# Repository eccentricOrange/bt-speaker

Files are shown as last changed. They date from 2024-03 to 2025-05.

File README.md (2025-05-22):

# Speaker Driver

This is a simple analog speaker driver, mostly driven simply by the goal of learning more about this field.

## Features

### Cross-over filtration
The driver is designed to support two drivers, one for bass and one for treble. The cross-over frequency is **1326 Hz**, and is achieved by using simple first order filters.

*   Capacitor: 10 uF
*   Resistor: 12R

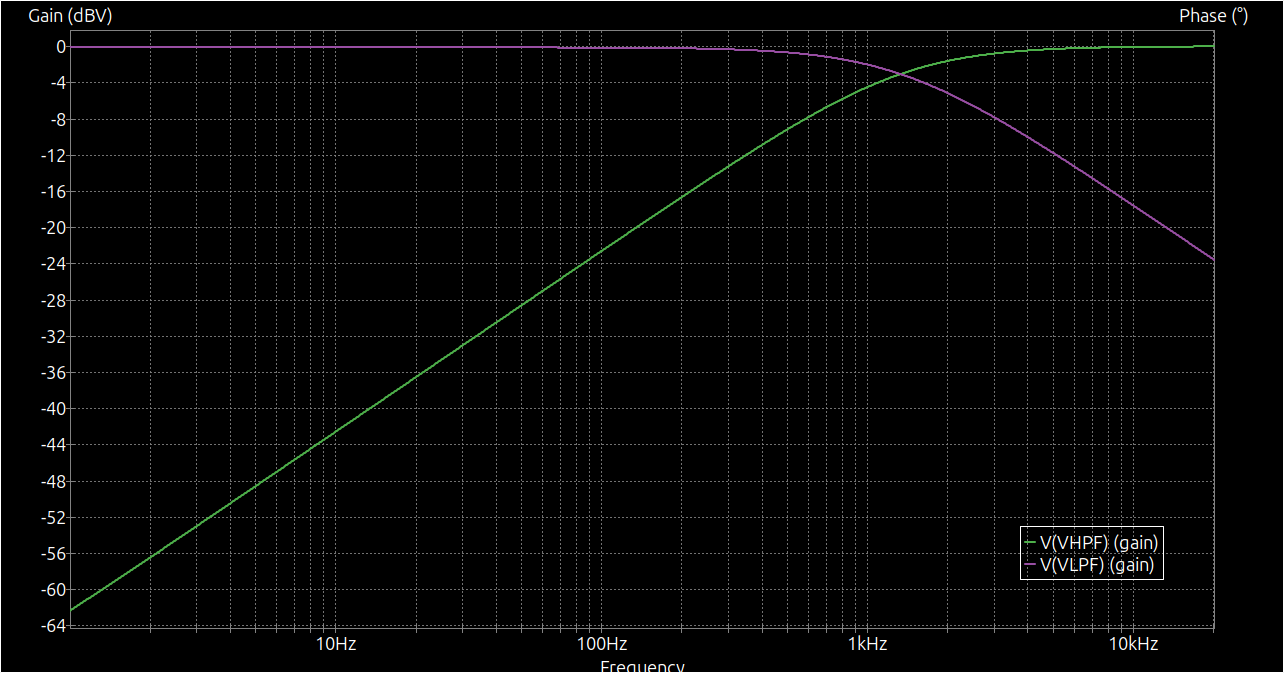
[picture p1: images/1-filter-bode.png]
bode


### Voltage pre-amplification
The input voltage is amplified by a factor of 6, using a simple non-inverting amplifier (LM741 op-amp). It is expected that the input voltage is around **1 V amplitude (2 Vpp)**, delivered by a 3.5 mm audio connector.

*   Input resistor: 820R
*   Fixed feedback resistor: 10k
*   Variable feedback resistor: 10k (in parallel with the fixed resistor)

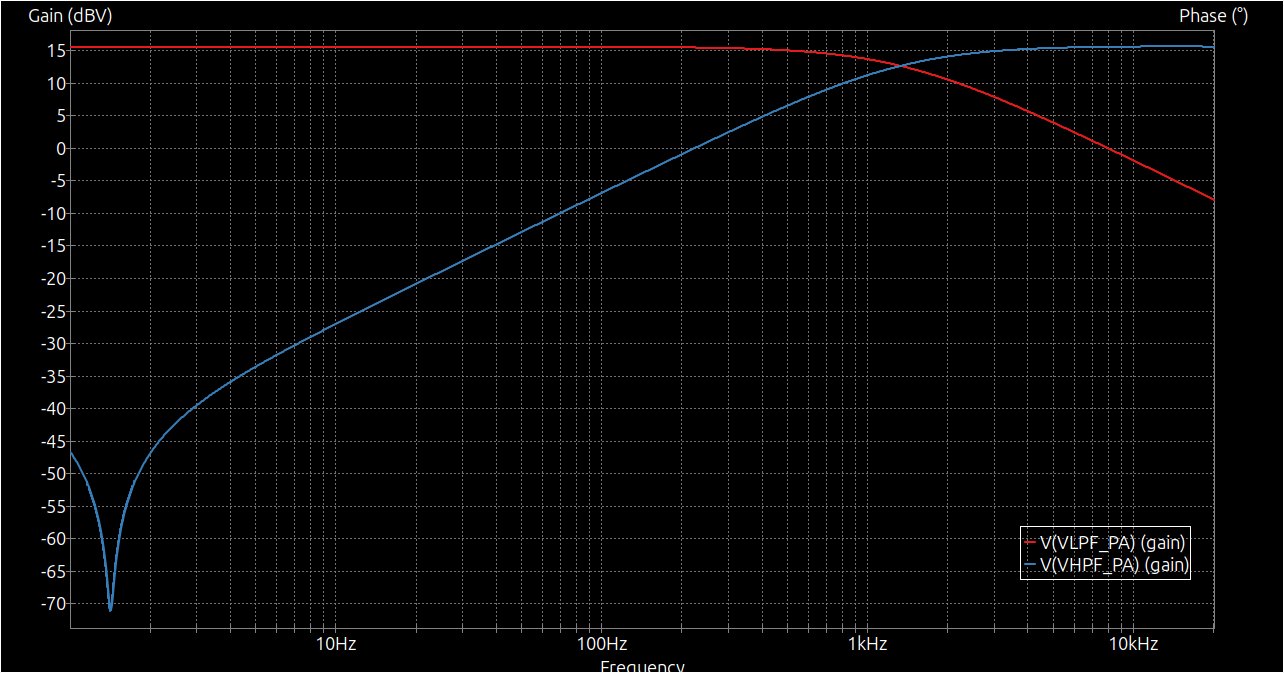
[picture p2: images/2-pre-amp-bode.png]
bode


### Power amplification
The next stage is a power amplifier, which is a simple class AB amplifier, that allows each driver to draw up to about **5W**. Each driver is expected to have an impedance of **4 Ohm**. TIP31 and TIP32 power transistors are used.

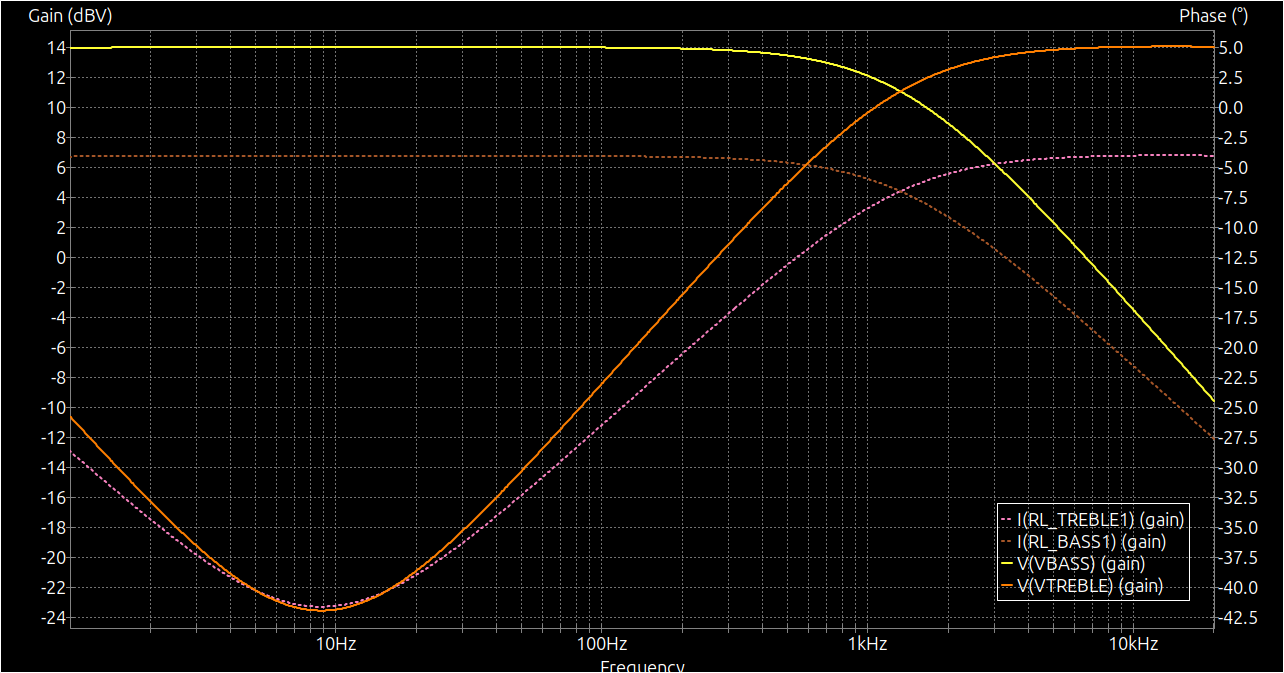
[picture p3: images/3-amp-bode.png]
bode


### Power supply
The PCB takes a single 24VDC 1A barrel jack input, and divides the voltage into 12VDC and -12VDC using a simple voltage divider.

## Result
The final assembled two-way speaker system with custom PCB is shown below

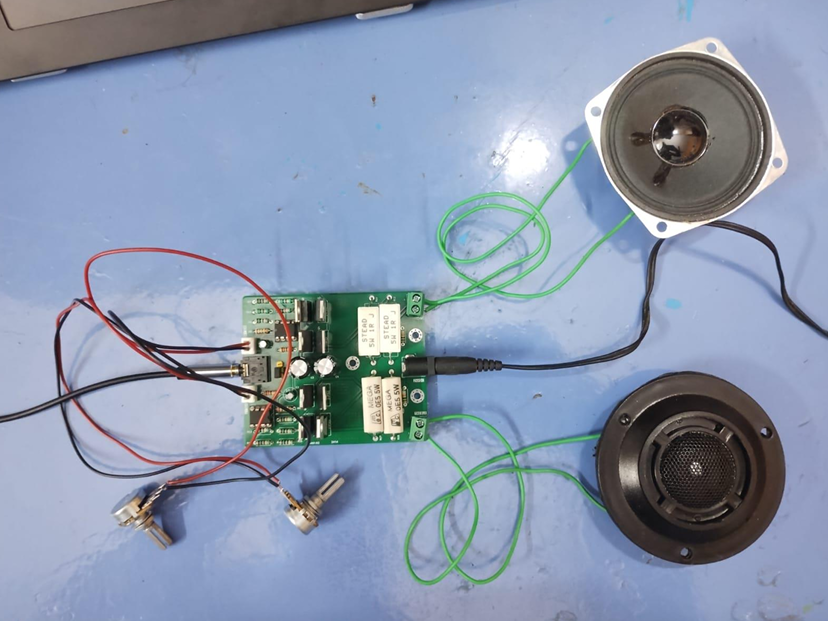
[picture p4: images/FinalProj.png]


## Future work
*   Miniaturize the PCB, using at least SMD components, if not a pre-made amplifier IC.
*   Understand, measure, and reduce the signal-to-noise ratio.
*   Use dedicated battery control circuitry for portable use.
*   Add Bluetooth connectivity (ideally BLE), using a microcontroller.
    *   Ideally, use custom firmware and design a custom antenna on the PCB.
    *   Alternatively, use an ESP32 module with a pre-made antenna.
*   Use buttons for power ON/OFF, volume control, and Bluetooth pairing.

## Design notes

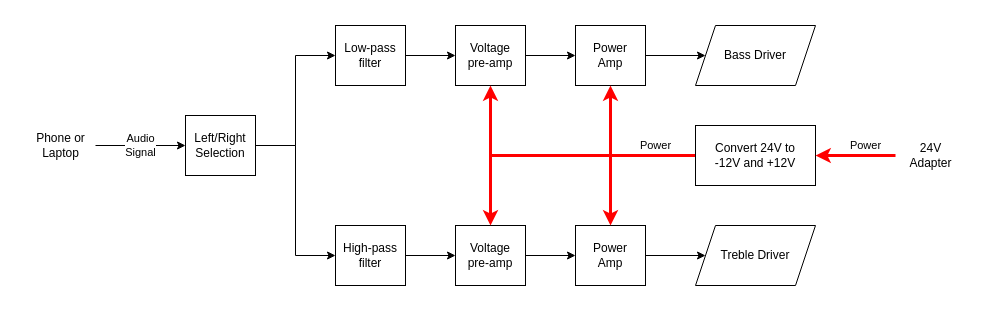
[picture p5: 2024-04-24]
images/4-over-all-design.png

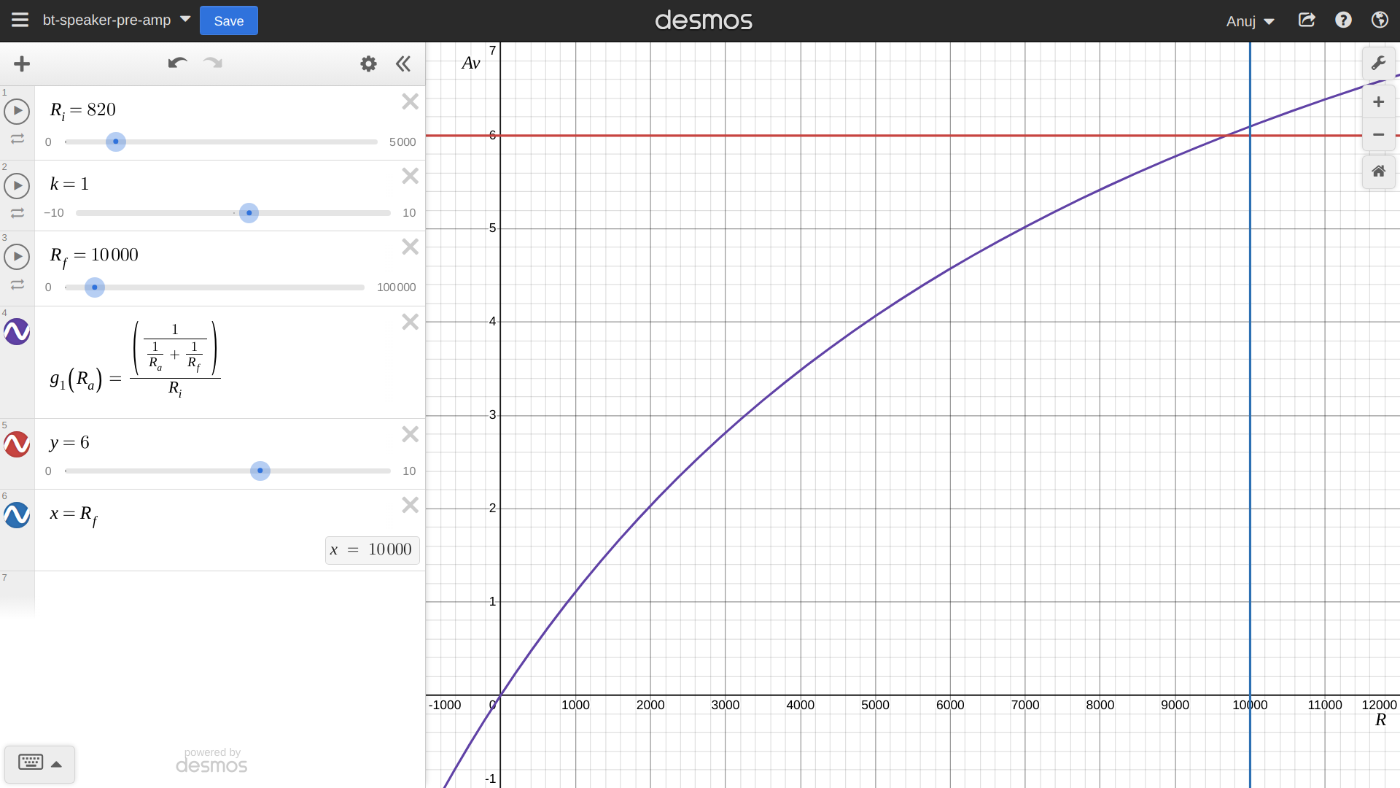
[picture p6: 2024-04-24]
images/6-gain-graph.png

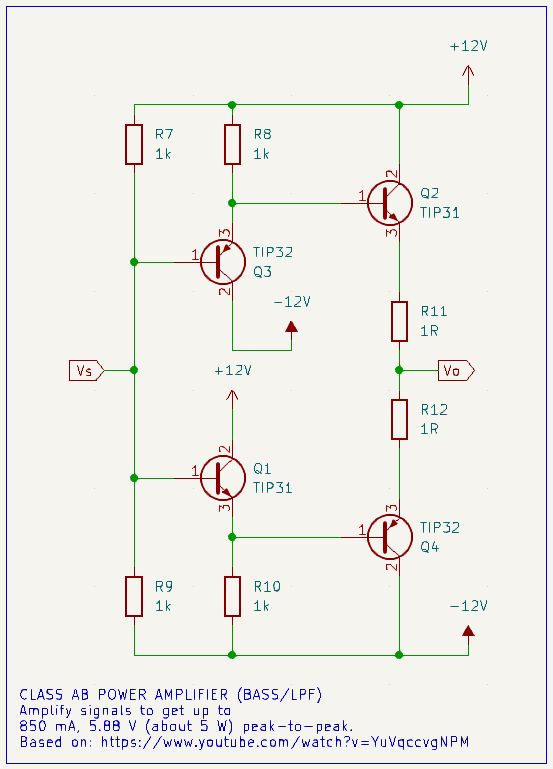
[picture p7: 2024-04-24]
images/7-class-ab-amp.png

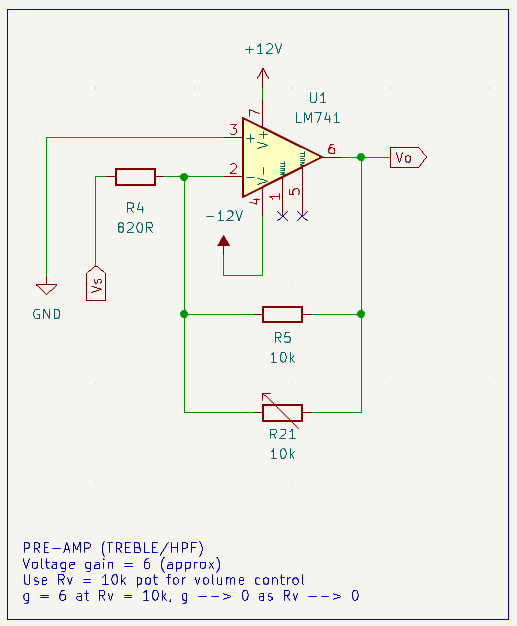
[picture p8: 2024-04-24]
images/5-pre-amp.png

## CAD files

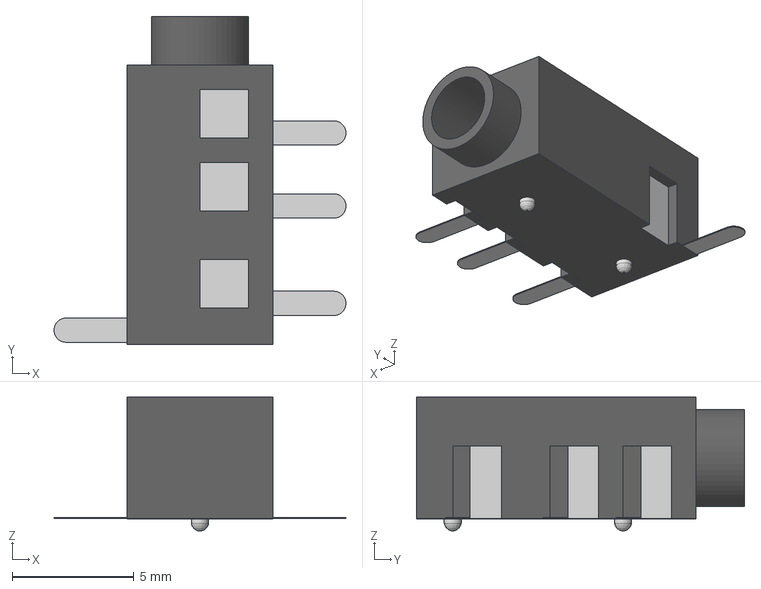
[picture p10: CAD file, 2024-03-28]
pcbs/3d-libs/audio-3-5mm-trrs-1.snapshot.3/audio_3.5mm_trrs.step
12.0 x 13.5 x 5.50 mm

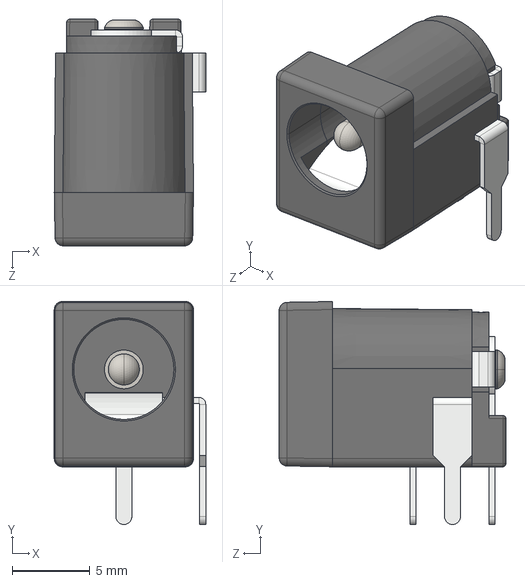
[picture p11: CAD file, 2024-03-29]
pcbs/3d-libs/dc-power-jack-5-5mm-x-2-1mm-2-54mm-pitch-1.snapshot.5/DC Power Jack 5.5mm x 2.1mm.STEP
9.77 x 14.4 x 14.6 mm

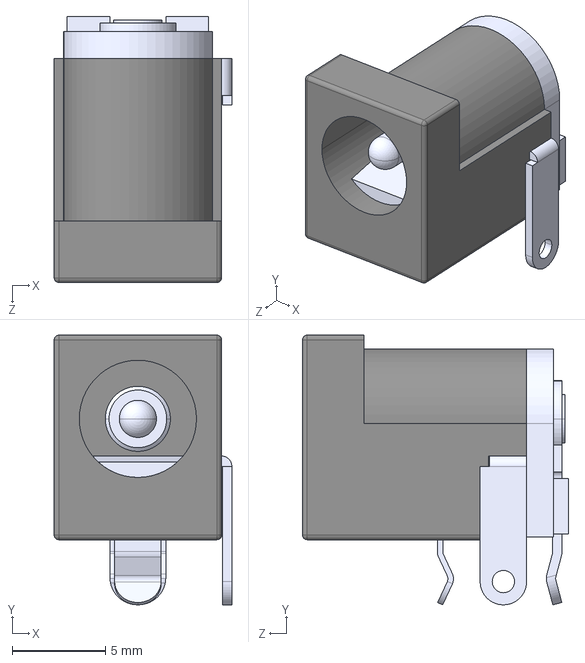
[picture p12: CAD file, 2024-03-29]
pcbs/3d-libs/DCJ200-10-A-K1-K--3DModel-STEP-740395.STEP
9.55 x 14.5 x 14.3 mm

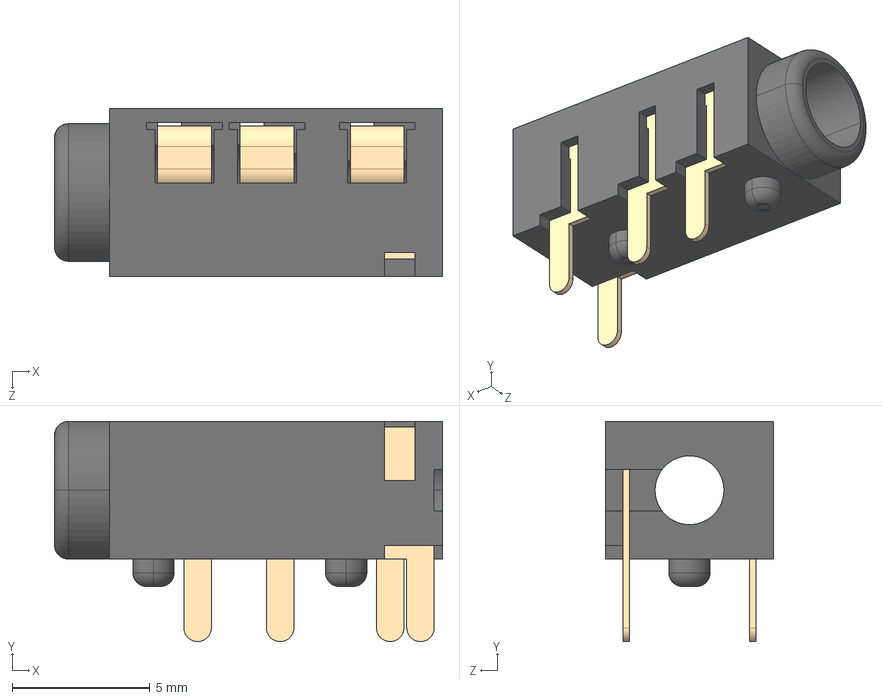
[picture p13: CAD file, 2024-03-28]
pcbs/3d-libs/PJ320A/PJ320A.STEP
14.1 x 8.00 x 6.10 mm
PJ320A蝶褲
PJ320A-Pin-A x 3
PJ320A-Pin-B

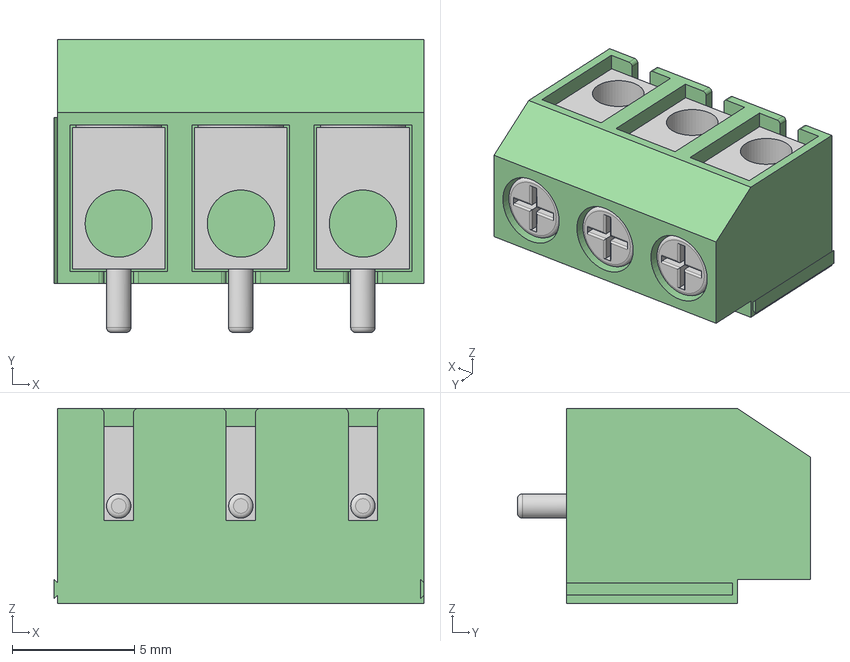
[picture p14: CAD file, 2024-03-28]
pcbs/3d-libs/screw-terminal-block-5mm-2.snapshot.17/Screw Terminal Block 5mm 3-way.step
15.2 x 12.0 x 8.00 mm

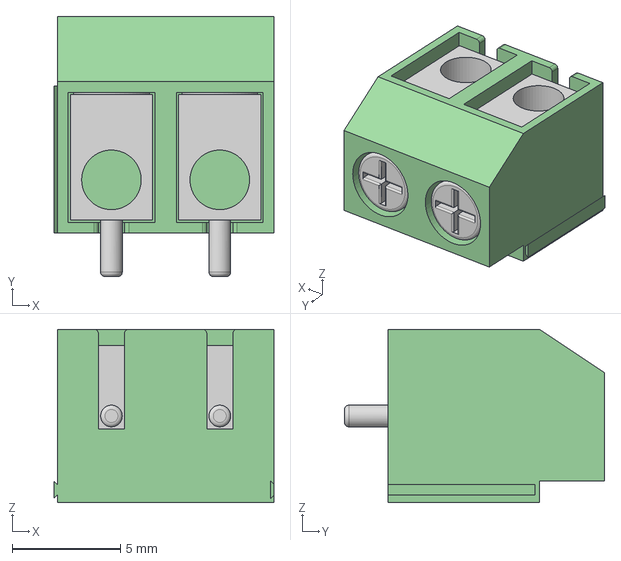
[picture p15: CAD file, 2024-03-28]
pcbs/3d-libs/screw-terminal-block-5mm-2.snapshot.17/Screw Terminal Block 5mm 2-way.step
10.2 x 12.0 x 8.00 mm

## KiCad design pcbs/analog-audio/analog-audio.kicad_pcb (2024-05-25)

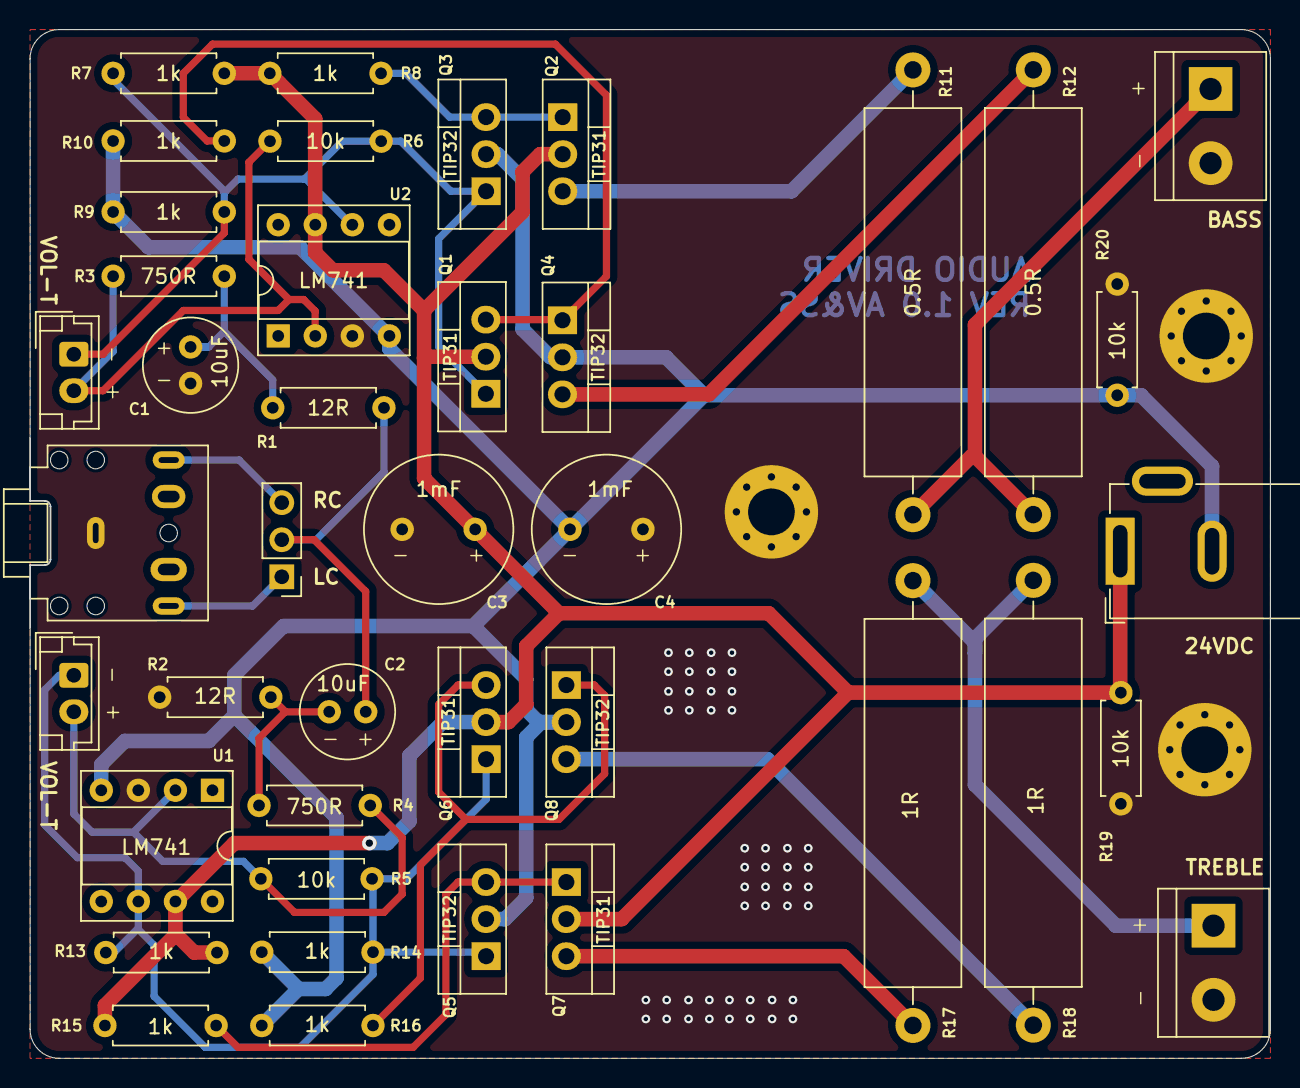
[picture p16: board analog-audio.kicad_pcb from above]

Board: 2 copper layers, 85.0 x 70.5 mm, 44 parts (0 on the bottom side), 22 nets.

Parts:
C1, C2: 10uF; C_Radial_D6.3mm_H11.0mm_P2.50mm
C3, C4: 1mF; C_Radial_D10.0mm_H12.5mm_P5.00mm
H1, H2, H3: MountingHole_Pad; MountingHole_3.2mm_M3_Pad_Via
J1: AudioJack5; Jack_3.5mm_CUI_SJ1-3525N_Horizontal
J2: 24VDC; BarrelJack_GCT_DCJ200-10-A_Horizontal
J3, J4: VOL-T; JST_EH_B2B-EH-A_1x02_P2.50mm_Vertical
J5: BASS; TerminalBlock_bornier-2_P5.08mm
J6: TREBLE; TerminalBlock_bornier-2_P5.08mm
J7: Channel; PinHeader_1x03_P2.54mm_Vertical
Q1, Q2, Q6, Q7: TIP31; TO-220-3_Vertical
Q3, Q4, Q5, Q8: TIP32; TO-220-3_Vertical
R1, R2: 12R; R_Axial_DIN0207_L6.3mm_D2.5mm_P7.62mm_Horizontal
R3, R4: 750R; R_Axial_DIN0207_L6.3mm_D2.5mm_P7.62mm_Horizontal
R5, R6, R19, R20: 10k; R_Axial_DIN0207_L6.3mm_D2.5mm_P7.62mm_Horizontal
R7, R8, R9, R10, R13, R14, R15, R16: 1k; R_Axial_DIN0207_L6.3mm_D2.5mm_P7.62mm_Horizontal
R11, R12: 0.5R; R_Axial_Power_L25.0mm_W6.4mm_P30.48mm
R17, R18: 1R; R_Axial_Power_L25.0mm_W6.4mm_P30.48mm
U1, U2: LM741; DIP-8_W7.62mm_Socket

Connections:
0: C1.1, C3.2, C4.1, H1.1, H2.1, H3.1, J1.S, J5.2, J6.2, R2.2, R19.2, R20.1, U1.3 (+), U2.3 (+)
+12V: C3.1, J2.1, Q1.2 (C), Q2.2 (C), Q6.2 (C), Q7.2 (C), R7.1, R8.1, R13.1, R15.1, R19.1, U1.7 (V+), U2.7 (V+)
-12V: C4.2, J2.2, Q3.2 (C), Q4.2 (C), Q5.2 (C), Q8.2 (C), R9.2, R10.2, R14.2, R16.2, R20.2, U1.4 (V-), U2.4 (V-)
L: J1.T, J7.1
unnamed: J3.2, R4.2, R5.1, U1.2 (-)
unnamed: J4.2, R3.2, R6.1, U2.2 (-)
unnamed: Q1.3 (E), Q4.1 (B), R10.1
unnamed: Q2.1 (B), Q3.3 (E), R8.2
unnamed: Q2.3 (E), R11.1
unnamed: Q4.3 (E), R12.2
unnamed: Q5.3 (E), Q7.1 (B), R15.2
unnamed: Q6.3 (E), Q8.1 (B), R16.1
unnamed: Q7.3 (E), R17.1
unnamed: Q8.3 (E), R18.2
R: J1.R1, J7.3
VBASS: J5.1, R11.2, R12.1
VHPF: C2.2, R2.1, R4.1
VHPF_PA: J3.1, Q5.1 (B), Q6.1 (B), R5.2, R13.2, R14.1, U1.6
VLPF: C1.2, R1.2, R3.1
VLPF_PA: J4.1, Q1.1 (B), Q3.1 (B), R6.2, R7.2, R9.1, U2.6
VTREBLE: J6.1, R17.2, R18.1
Vs: C2.1, J7.2, R1.1

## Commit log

2024-03-28 set kicad path
    [analog-audio.kicad_pcb]
2024-03-29 re-designed for power
    [DC Power Jack 5.5mm x 2.1mm.STEP, DCJ200-10-A-K1-K--3DModel-STEP-740395.STEP, analog-audio.kicad_pcb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]
2024-03-29 added volume control
    [analog-audio.kicad_pcb, analog-audio.kicad_sch]
2024-03-29 clean up schematic
    [analog-audio.kicad_pcb, analog-audio.kicad_sch]
2024-03-30 successful sims?
    [analog-audio.kicad_sch]
2024-03-31 successful sims!!
    [analog-audio.kicad_sch]
2024-03-31 vias and +- silkscreen
    [analog-audio.kicad_pcb]
2024-04-01 add mounting holes
    [analog-audio.kicad_pcb, analog-audio.kicad_sch]
2024-05-25 fixed simulations and updated schematic for real values
    [analog-audio.kicad_sch]
2024-05-25 fixed error in PCB and updated to use real values
    [analog-audio.kicad_pcb, analog-audio.kicad_sch]
